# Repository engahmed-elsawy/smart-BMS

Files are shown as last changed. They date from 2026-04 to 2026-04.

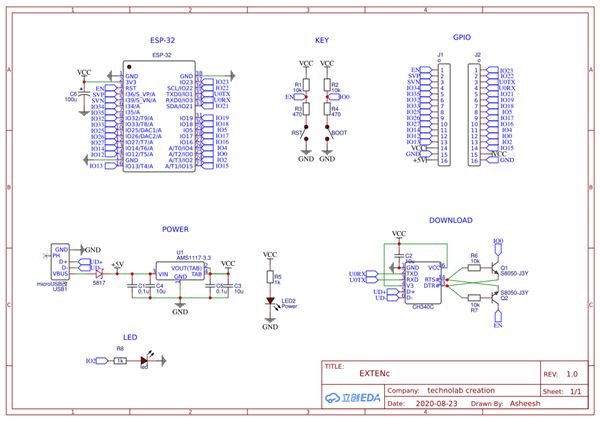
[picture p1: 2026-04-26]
PCB Design/f37d51bfc36943d1b52e4bf3738da4ba_1.jpg

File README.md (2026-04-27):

# ESP32 Smart BMS

An open-source Battery Management System for 6S Li-ion packs built around an ESP32.
The project covers hardware design, embedded firmware, and a planned machine learning
pipeline that will train on the data the system collects.

---

## Project Status

| Phase | Status |
|---|---|
| Hardware design (schematic + PCB) | ✅ Done |
| Firmware v1 — Coulomb Counting + Web Dashboard | ✅ Done |
| Firmware v2 — MQTT data pipeline | ✅ Done |
| ML model — SOC / SOH estimation | 🔜 Planned |

---

## Repository Structure

```
esp32-smart-bms/
│
├── hardware/
│   └── schematic/               BMS schematic (KiCad / PDF)
│
├── esp32_bms_coulomb/           Firmware v1 — Web dashboard only
│   ├── esp32_bms_coulomb.cpp
│   └── README.md
│
├── esp32_bms_mqtt/              Firmware v2 — Web dashboard + MQTT
│   ├── esp32_bms_coulomb_mqtt.cpp
│   └── README.md
│
└── README.md                    ← this file
```

---

## What the System Does

```
┌─────────────────────────────────────────────────────────┐
│                     6S Li-ion Pack                      │
│  Cell 1 │ Cell 2 │ Cell 3 │ Cell 4 │ Cell 5 │ Cell 6   │
└────┬─────────┬────────┬────────┬────────┬────────┬──────┘
     │         │        │        │        │        │
     └─────────┴────────┴───── CD4051 ────┴────────┘
                                  │
                              ESP32 ADC
                                  │
              ┌───────────────────┼───────────────────┐
              │                   │                   │
        Web Dashboard          MQTT Broker        Serial Monitor
        (browser, live)     (Home Assistant /    (115200 baud)
                              Grafana / ML)
                                  │
                          ┌───────┴───────┐
                          │  (planned)    │
                       Dataset CSV    ML Model
                      (SOC / SOH /   (TensorFlow
                       temperature)    Lite / sklearn)
```

---

## Hardware Overview

### Core Components

| Component | Role |
|---|---|
| ESP32 DevKit | Main MCU — ADC, Wi-Fi, control logic |
| CD4051 | 8-channel analog MUX — reads all cells through one ADC pin |
| ACS712 (or similar) | Current sensor — measures pack charge / discharge current |
| Voltage dividers | Scale each cell voltage and pack voltage down to ≤ 3.3 V |
| MOSFETs / transistors | Balance outputs — one per cell |

### Key Design Decisions

**Single ADC pin via MUX** — The CD4051 lets the ESP32 read 8 analog channels
through a single ADC input. This saves GPIOs and avoids the inter-channel
crosstalk that comes from using multiple ADC pins simultaneously on the ESP32.

**All analog signals ≤ 3.3 V** — The ESP32 ADC is not 5 V tolerant.
Every voltage divider and sensor output is designed to stay within 0–3.3 V.

**ADC1 only** — ADC2 on the ESP32 is shared with the Wi-Fi radio and gives
unreliable readings when Wi-Fi is active. `PIN_MUX_OUT` is wired to a GPIO
in the ADC1 group (GPIO 32–39).

**Hardware schematic** is in the `hardware/schematic/` folder.

---

## Firmware

### v1 — Web Dashboard (`esp32_bms_coulomb/`)

Standalone firmware. No external services needed.

- Reads all 8 MUX channels every 300 ms
- Coulomb Counting SOC with voltage re-sync at rest
- Auto cell balancing (configurable thresholds)
- Live browser dashboard with 4 Chart.js graphs — updates every second
- JSON API at `/api/status` and `/api/history`

### v2 — MQTT (`esp32_bms_mqtt/`)

Everything in v1, plus:

- Publishes to MQTT broker every 5 seconds
- Individual topics per value (`bms/soc`, `bms/cell/1`, etc.)
- Subscribes to command topics for remote balance control
- Compatible with Home Assistant, Node-RED, Grafana, and any MQTT client
- **All published data is logged by the broker** — this is the dataset that
  will feed the ML pipeline

See each folder's `README.md` for full setup instructions.

---

## MQTT Data Format

Every publish cycle sends these topics:

```
bms/status         →  full JSON snapshot
bms/soc            →  67.4
bms/pack_voltage   →  24.350
bms/pack_current   →  -2.100
bms/cell/1  …  /6  →  4.058  (one topic per cell)
bms/charged_ah     →  1.2340
bms/discharged_ah  →  3.5670
```

To log everything to a CSV file using Node-RED or a simple subscriber:

```bash
# log all bms topics to a file
mosquitto_sub -h 192.168.1.100 -t "bms/#" -v >> bms_log.txt
```

---

## ML Pipeline (Planned)

The MQTT broker accumulates time-series data across real charge / discharge cycles.
That dataset will be used to train a model that estimates SOC and SOH more
accurately than the current voltage-table approach.

### Planned Features

- **Better SOC estimation** — replace the voltage lookup table with a learned
  model that accounts for temperature, aging, and load history
- **SOH (State of Health)** — track capacity fade over hundreds of cycles
- **Anomaly detection** — flag unusual cell behavior (high self-discharge,
  internal short, accelerated aging)
- **Remaining useful life (RUL)** — predict how many cycles the pack has left

### Planned Stack

```
Data collection  →  MQTT broker  →  CSV / InfluxDB
Feature engineering  →  Python (pandas, numpy)
Model training   →  scikit-learn / TensorFlow / PyTorch
Deployment       →  TensorFlow Lite on ESP32  or  inference on a Pi / server
```

### Features the Model Will Use

| Feature | Source |
|---|---|
| Cell voltages (V1–V6) | `bms/cell/1` … `/6` |
| Pack current (A) | `bms/pack_current` |
| Pack voltage (V) | `bms/pack_voltage` |
| SOC from Coulomb Counting | `bms/soc` |
| Charged Ah | `bms/charged_ah` |
| Discharged Ah | `bms/discharged_ah` |
| Timestamp | logged by subscriber |
| Temperature (future) | planned sensor addition |

### Data Collection Advice

The more cycles logged, the better the model. To build a useful dataset:

1. Flash the v2 MQTT firmware.
2. Set up a broker and a subscriber that appends every message to a CSV with a timestamp.
3. Run the pack through full charge / discharge cycles under realistic loads.
4. Aim for at least 20–30 full cycles before starting model training.

---

## Quick Start

### 1. Flash the firmware

1. Install [Arduino IDE 2.x](https://www.arduino.cc/en/software).
2. Add the ESP32 board package URL in `File → Preferences`:
   ```
   https://raw.githubusercontent.com/espressif/arduino-esp32/gh-pages/package_esp32_index.json
   ```
3. Open `esp32_bms_coulomb/esp32_bms_coulomb.cpp`.
4. Set your Wi-Fi credentials and GPIO pins in the **USER CONFIG** section.
5. Set `packCapacityAh` to your pack's real capacity.
6. Flash to your ESP32.

### 2. Open the dashboard

Find the IP in Serial Monitor (115200 baud) and open it in a browser.

### 3. Add MQTT (optional)

Switch to the `esp32_bms_mqtt/` version, install **PubSubClient**, set
`MQTT_BROKER` to your broker's IP, and reflash.

---

## Calibration Checklist

Before trusting the readings, go through this checklist:

- [ ] Measure each cell voltage with a multimeter and calculate the correct `cellScale[i]`
- [ ] Measure pack voltage and calculate the correct `packScale`
- [ ] Verify current sensor zero-current offset matches `currentOffsetV`
- [ ] Set `packCapacityAh` to the actual rated capacity of your cells
- [ ] Update the SOC voltage table if your cells have a different chemistry

---

## Contributing

Pull requests are welcome. If you are working on the ML pipeline, data collection
scripts, or a new sensor integration, open an issue first to discuss the approach.

---

## License

MIT

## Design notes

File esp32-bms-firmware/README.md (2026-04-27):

# ESP32 BMS — Coulomb Counting + Live Web Dashboard

ESP32 firmware for monitoring a 6S Li-ion battery pack.
Reads 6 cells + pack current + pack voltage through a CD4051 analog MUX,
estimates SOC using Coulomb Counting, and serves a live dashboard in the browser.

---

## Repository Structure

```
esp32_bms_coulomb/
└── esp32_bms_coulomb.cpp
```

---

## Requirements

### Hardware

| Component | Details |
|---|---|
| ESP32 DevKit | Any standard ESP32 board |
| CD4051 | 8-channel analog multiplexer |
| Current sensor | ACS712 or similar (output 0–3.3 V) |
| Voltage dividers | One per cell + one for pack — output must be ≤ 3.3 V |
| Balancing circuit | MOSFET or transistor per cell |

### Software

- [Arduino IDE](https://www.arduino.cc/en/software) version 2.x
- **ESP32 board package** — in Arduino IDE:  
  `File → Preferences → Additional boards manager URLs`, add:
  ```
  https://raw.githubusercontent.com/espressif/arduino-esp32/gh-pages/package_esp32_index.json
  ```
  Then `Tools → Board → Boards Manager`, search for **esp32** and install it.

No additional libraries are needed — the code uses `WiFi.h` and `WebServer.h`
which ship with the ESP32 package.

---

## Configuration

Open `esp32_bms_coulomb.cpp` and edit the **USER CONFIG** section at the top.

### 1. Wi-Fi credentials

```cpp
const char* WIFI_SSID = "YOUR_WIFI_SSID";    // your Wi-Fi network name
const char* WIFI_PASS = "YOUR_WIFI_PASSWORD"; // your Wi-Fi password
```

### 2. GPIO pin mapping

```cpp
static const int PIN_MUX_S0  = 25;   // MUX select bit 0
static const int PIN_MUX_S1  = 26;   // MUX select bit 1
static const int PIN_MUX_S2  = 27;   // MUX select bit 2
static const int PIN_MUX_OUT = 34;   // MUX output → ADC (use GPIO 32–39 only)

static const int PIN_BAL_1 = 16;     // balance output — cell 1
static const int PIN_BAL_2 = 17;
static const int PIN_BAL_3 = 18;
static const int PIN_BAL_4 = 19;
static const int PIN_BAL_5 = 21;
static const int PIN_BAL_6 = 22;
```

Change these numbers to match your actual wiring.

### 3. Voltage calibration

```cpp
// cell_V = adc_V × cellScale  — one scale factor per cell
float cellScale[6] = { 1.400f, 1.400f, 1.400f, 1.400f, 1.400f, 1.400f };

// pack_V = adc_V × packScale
float packScale = 9.125f;

// current sensor:  I(A) = (adc_V - offset) × gain
// ACS712-20A example: offset = 1.65 V, gain = 10.0 A/V
float currentOffsetV   = 1.650f;
float currentGainAperV = 10.000f;
```

**How to calibrate `cellScale`:**  
Measure the real cell voltage with a multimeter, then read the ADC voltage
for the same channel from Serial Monitor.
```
cellScale = real_voltage / adc_voltage
```
Example: multimeter reads 3.80 V, ADC reads 0.271 V → `cellScale = 14.02`

### 4. Pack capacity (Coulomb Counting)

```cpp
// Set this to the real capacity of your pack in Ah
float packCapacityAh = 10.0f;
```

---

## MUX Channel Mapping (CD4051)

| Channel | Signal | Description |
|---|---|---|
| CH0 | ADC_C1 | Cell 1 voltage |
| CH1 | ADC_C2 | Cell 2 voltage |
| CH2 | ADC_C3 | Cell 3 voltage |
| CH3 | ADC_C4 | Cell 4 voltage |
| CH4 | ADC_C5 | Cell 5 voltage |
| CH5 | ADC_C6 | Cell 6 voltage |
| CH6 | ADC_ip | Pack current |
| CH7 | ADC_vb | Pack voltage |

---

## Web Dashboard

After flashing, open Serial Monitor at **115200 baud**. You will see:

```
Connected — IP: 192.168.1.45
HTTP server started.
```

Open a browser on any device on the same network and go to:

```
http://192.168.1.45/
```

The page updates every second without reloading.

### What the dashboard shows

- **Pack Voltage** and **Pack Current** — live readings
- **SOC (Coulomb Counting)** with a color bar (green → yellow → red as it drops)
- **SOC (Voltage)** — reference value for comparison
- **Charged Ah / Discharged Ah** — cumulative totals since boot
- **6 cell cards** — individual voltages, highlighted when balancing is active
- **4 live charts** — SOC %, Pack Voltage, Pack Current, and all Cell Voltages

### HTTP Endpoints

| URL | Description |
|---|---|
| `http://[IP]/` | Main live dashboard |
| `http://[IP]/api/status` | Full JSON snapshot of all values |
| `http://[IP]/api/history` | Last 200 data points as arrays (used by charts) |
| `http://[IP]/balance/off` | Turn off all balance outputs |
| `http://[IP]/balance/auto/on` | Enable automatic balancing |
| `http://[IP]/balance/auto/off` | Disable automatic balancing |
| `http://[IP]/balance/set?cell=3&state=1` | Manually switch one cell on (state=1) or off (state=0) |

---

## Coulomb Counting — How It Works

1. **First boot:** SOC is seeded from the voltage lookup table since no current history exists yet.
2. **During operation:** integrates `dSOC = I × dt / capacity × 100` every 300 ms.
   - Positive current (charging) → multiplied by `chargeEfficiency`.
   - Negative current (discharging) → divided by `dischargeEfficiency`.
3. **Rest re-sync:** when `|I| < 0.2 A` for 60 consecutive seconds the pack is
   considered at rest. The voltage-based SOC then gently corrects any accumulated
   integration drift using a 90 % CC + 10 % voltage blend per cycle.

---

## Serial Monitor Output

A report is printed every 2 seconds:

```
====================================================
Samples : 1547
Pack    : 24.350 V | -2.100 A
SOC (CC): 67.45 %  |  SOC (V): 65.20 %
Charged : 0.0000 Ah  |  Discharged: 0.1234 Ah
Cell 1  : 4.058 V  BAL=OFF
Cell 2  : 4.061 V  BAL=OFF
Cell 3  : 4.055 V  BAL=OFF
Cell 4  : 4.059 V  BAL=OFF
Cell 5  : 4.060 V  BAL=OFF
Cell 6  : 4.057 V  BAL=OFF
Raw ADC:
  CH0 (ADC_C1): raw=336  adc=0.2710 V
  ...
```

---

## Next Step

If you need to push data to Home Assistant, Grafana, or control the BMS
remotely over the network — see the MQTT version in the `esp32_bms_mqtt` folder.

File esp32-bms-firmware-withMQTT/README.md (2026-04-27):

# ESP32 BMS — Coulomb Counting + Live Dashboard + MQTT

Extended version of the BMS firmware that adds MQTT on top of the web dashboard.
The ESP32 publishes live battery data to a broker every 5 seconds and accepts
remote commands to control cell balancing from any device on the network.

> The web dashboard from `esp32_bms_coulomb` is still fully functional in this
> version — MQTT is added on top without removing anything.

---

## Repository Structure

```
esp32_bms_mqtt/
└── esp32_bms_coulomb.cpp
```

---

## Additional Requirements

### Extra Library

**PubSubClient** by Nick O'Leary

**Arduino IDE:**  
`Sketch → Include Library → Manage Libraries` → search for `PubSubClient` → Install

**PlatformIO** — add to `platformio.ini`:
```ini
lib_deps = knolleary/PubSubClient @ ^2.8
```

### MQTT Broker

You need a running MQTT broker accessible from the ESP32.

| Option | Best for | Setup |
|---|---|---|
| **Mosquitto** on Raspberry Pi or PC | Permanent local use | `sudo apt install mosquitto mosquitto-clients` |
| **Home Assistant** built-in broker | If you already run HA | Enable the Mosquitto add-on inside HA |
| **HiveMQ Cloud** (free tier) | Cloud access, no local server | [hivemq.com/mqtt-cloud-broker](https://www.hivemq.com/mqtt-cloud-broker/) |
| **test.mosquitto.org** | Quick testing only | Public broker — do not use in production |

---

## Configuration

Open `esp32_bms_coulomb.cpp` and edit the **USER CONFIG** section at the top.

### 1. Wi-Fi credentials

```cpp
const char* WIFI_SSID = "YOUR_WIFI_SSID";    // your Wi-Fi network name
const char* WIFI_PASS = "YOUR_WIFI_PASSWORD"; // your Wi-Fi password
```

### 2. MQTT broker address ← most important step

```cpp
const char* MQTT_BROKER   = "192.168.1.100"; // ← IP or hostname of your broker
const uint16_t MQTT_PORT  = 1883;            // default MQTT port (use 8883 for TLS)
const char* MQTT_USER     = "";              // leave empty if no authentication
const char* MQTT_PASS_STR = "";              // leave empty if no authentication
const char* MQTT_CLIENT_ID    = "esp32_bms_01"; // unique name for this device
const char* MQTT_TOPIC_PREFIX = "bms";          // all topics will start with this
```

**How to find your broker IP:**

- **Mosquitto on Raspberry Pi:** the broker IP is the Pi's IP address.  
  Run `hostname -I` in the Pi terminal to find it.
- **Mosquitto on Windows/Linux PC:** use the machine's local IP.  
  On Windows: `ipconfig` in Command Prompt → look for IPv4 Address.  
  On Linux: `ip a` → look for your network interface IP.
- **Home Assistant:** go to `Settings → System → Network` to find the HA IP.
- **HiveMQ Cloud:** your dashboard provides a hostname — paste it in place of the IP  
  and change `MQTT_PORT` to `8883`. TLS support requires additional setup.
- **Quick test (no broker):** set `MQTT_BROKER = "test.mosquitto.org"` temporarily.

**If your broker requires a username and password:**

```cpp
const char* MQTT_USER     = "myusername";
const char* MQTT_PASS_STR = "mypassword";
```

### 3. Publish interval

```cpp
// How often to publish data in milliseconds — keep at 1000 or above
const uint32_t MQTT_PUBLISH_INTERVAL_MS = 5000;  // every 5 seconds
```

### 4. Disable MQTT without removing the code

```cpp
bool mqttEnabled = false;   // web dashboard still works normally
```

---

## Topics Published by the ESP32

All topics start with the prefix defined in `MQTT_TOPIC_PREFIX` (default: `bms`).

| Topic | Type | Example value |
|---|---|---|
| `bms/status` | Full JSON | `{"samples":1200,"pack_voltage":24.35,...}` |
| `bms/soc` | Number | `67.4` |
| `bms/pack_voltage` | Number | `24.350` |
| `bms/pack_current` | Number | `-2.100` |
| `bms/cell/1` | Number | `4.058` |
| `bms/cell/2` | Number | `4.061` |
| `bms/cell/3` | Number | `4.055` |
| `bms/cell/4` | Number | `4.059` |
| `bms/cell/5` | Number | `4.060` |
| `bms/cell/6` | Number | `4.057` |
| `bms/charged_ah` | Number | `1.2340` |
| `bms/discharged_ah` | Number | `3.5670` |

---

## Command Topics (ESP32 subscribes)

Send a message to these topics to control the BMS remotely.

| Topic | Payload | Result |
|---|---|---|
| `bms/cmd/balance_auto` | `ON` | Enable automatic balancing |
| `bms/cmd/balance_auto` | `OFF` | Disable automatic balancing |
| `bms/cmd/balance_all` | `OFF` | Force all balance outputs off |
| `bms/cmd/balance_set` | `3:1` | Turn cell 3 balance on manually |
| `bms/cmd/balance_set` | `3:0` | Turn cell 3 balance off manually |

**Examples using `mosquitto_pub` from a terminal:**

```bash
# Enable auto balance
mosquitto_pub -h 192.168.1.100 -t "bms/cmd/balance_auto" -m "ON"

# Turn off all balancing
mosquitto_pub -h 192.168.1.100 -t "bms/cmd/balance_all" -m "OFF"

# Manually turn on cell 2
mosquitto_pub -h 192.168.1.100 -t "bms/cmd/balance_set" -m "2:1"

# Manually turn off cell 2
mosquitto_pub -h 192.168.1.100 -t "bms/cmd/balance_set" -m "2:0"
```

**Monitor all topics from a terminal:**

```bash
# Subscribe to everything under the bms/ prefix
mosquitto_sub -h 192.168.1.100 -t "bms/#" -v

# Watch SOC only
mosquitto_sub -h 192.168.1.100 -t "bms/soc"
```

---

## Home Assistant Integration

Add the following to your `configuration.yaml`:

```yaml
mqtt:
  sensor:
    - name: "BMS SOC"
      state_topic: "bms/soc"
      unit_of_measurement: "%"
      device_class: battery

    - name: "BMS Pack Voltage"
      state_topic: "bms/pack_voltage"
      unit_of_measurement: "V"
      device_class: voltage

    - name: "BMS Pack Current"
      state_topic: "bms/pack_current"
      unit_of_measurement: "A"
      device_class: current

    - name: "BMS Charged Ah"
      state_topic: "bms/charged_ah"
      unit_of_measurement: "Ah"

    - name: "BMS Discharged Ah"
      state_topic: "bms/discharged_ah"
      unit_of_measurement: "Ah"

    - name: "BMS Cell 1"
      state_topic: "bms/cell/1"
      unit_of_measurement: "V"

    - name: "BMS Cell 2"
      state_topic: "bms/cell/2"
      unit_of_measurement: "V"

    - name: "BMS Cell 3"
      state_topic: "bms/cell/3"
      unit_of_measurement: "V"

    - name: "BMS Cell 4"
      state_topic: "bms/cell/4"
      unit_of_measurement: "V"

    - name: "BMS Cell 5"
      state_topic: "bms/cell/5"
      unit_of_measurement: "V"

    - name: "BMS Cell 6"
      state_topic: "bms/cell/6"
      unit_of_measurement: "V"

  switch:
    - name: "BMS Auto Balance"
      command_topic: "bms/cmd/balance_auto"
      payload_on: "ON"
      payload_off: "OFF"
```

---

## Serial Monitor Output

MQTT connection status is printed alongside the normal data report:

```
[MQTT] Connecting to 192.168.1.100… connected.
[MQTT] Subscribed to cmd topics.
====================================================
Samples : 1547
Pack    : 24.350 V | -2.100 A
SOC (CC): 67.45 %  |  SOC (V): 65.20 %
...
```

If the connection drops, the firmware retries automatically every 10 seconds:

```
[MQTT] Connecting to 192.168.1.100… failed (rc=-2) — will retry.
```

---

## Suggested Repository Structure

```
esp32-bms-firmware/
│
├── esp32_bms_coulomb/          ← v1 — Web dashboard only
│   ├── esp32_bms_coulomb.cpp
│   └── README.md
│
└── esp32_bms_mqtt/             ← v2 — Web dashboard + MQTT
    ├── esp32_bms_coulomb_mqtt.cpp
    └── README.md               ← this file

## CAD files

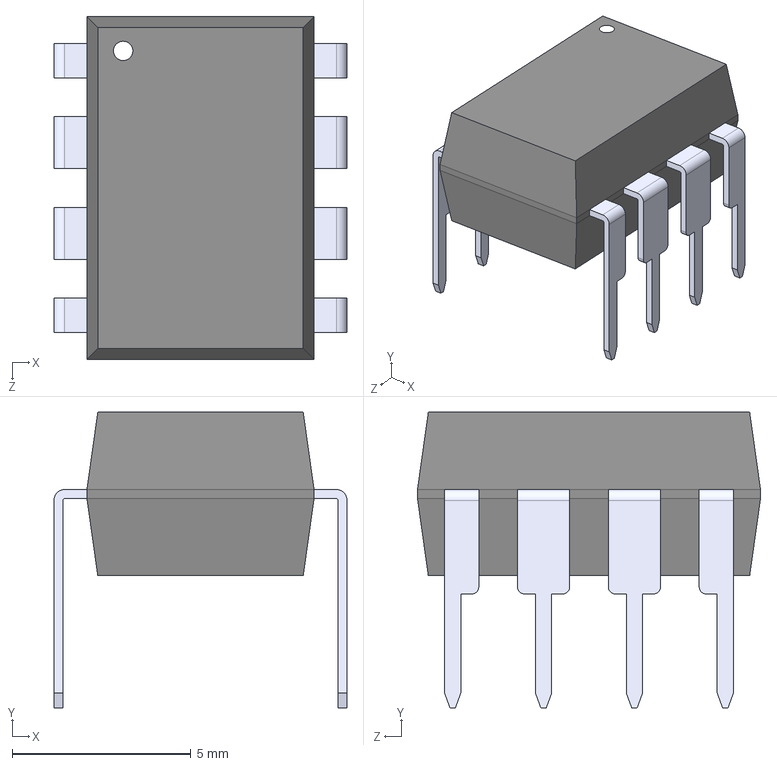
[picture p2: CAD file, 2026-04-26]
PCB Design/LM358P.STEP
8.19 x 8.26 x 9.59 mm

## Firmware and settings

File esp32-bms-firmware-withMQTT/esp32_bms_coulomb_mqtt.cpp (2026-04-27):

#include <WiFi.h>
#include <WebServer.h>
#include <PubSubClient.h>
#include <math.h>

/*
  ESP32 BMS Firmware — v2 — Coulomb Counting + Web Dashboard + MQTT
  ==================================================================
  Hardware: as per schematic (Ahmed Hatem Elsawy — 27/4/2026)
    - CD4051BM  8-ch MUX  (S0=IO25, S1=IO26, S2=IO27, OUT→GPIO34)
    - LM358P    differential cell voltage buffers (gain=0.5 per cell)
    - LM358P    pack voltage buffer  (R49=13K / R51=1.6K divider)
    - ACS712-30A current sensor, VCC=5V, through LM358 gain-2 amp
      + external 18K/33K voltage divider to protect ESP32 ADC
    - IRLZ44N   balancing MOSFETs via optocouplers

  Required library: PubSubClient by Nick O'Leary
    Arduino IDE  → Sketch → Include Library → Manage Libraries → "PubSubClient"
    PlatformIO   → lib_deps = knolleary/PubSubClient @ ^2.8

  Current sensor signal chain:
    ACS712-30A (VCC=5V) → zero=2.5V, sensitivity=66mV/A
    → LM358 gain-2  → zero=5.0V, gain=132mV/A
    → 18K/33K divider (×0.647) → zero=3.235V, gain=85.4mV/A
    → ESP32 ADC (safe ≤3.3V)
    currentGainAperV = 1 / 0.0854 = 11.7 A/V

  Cell voltage signal chain:
    Cell differential → LM358 unity buffer → 1M/1M divider → ADC
    cellScale = 2.0

  MUX channel mapping:
    CH0=ADC_C1, CH1=ADC_C2, CH2=ADC_C3, CH3=ADC_C4,
    CH4=ADC_C5, CH5=ADC_C6, CH6=ADC_ip, CH7=ADC_vb

  MQTT topics published  (prefix = MQTT_TOPIC_PREFIX, default "bms"):
    bms/status         full JSON snapshot
    bms/soc            SOC % (Coulomb)
    bms/pack_voltage   pack V
    bms/pack_current   pack A
    bms/cell/1…6       individual cell voltages
    bms/charged_ah     cumulative Ah in
    bms/discharged_ah  cumulative Ah out

  MQTT command topics (subscribed):
    bms/cmd/balance_auto   ON | OFF
    bms/cmd/balance_all    OFF
    bms/cmd/balance_set    "N:S"  e.g. "3:1" or "3:0"
*/

// =====================================================================
// USER CONFIG
// =====================================================================
const char* WIFI_SSID = "YOUR_WIFI_SSID";
const char* WIFI_PASS = "YOUR_WIFI_PASSWORD";

// ── MQTT ─────────────────────────────────────────────────────────────
const char*    MQTT_BROKER        = "192.168.1.100"; // ← your broker IP
const uint16_t MQTT_PORT          = 1883;
const char*    MQTT_USER          = "";   // leave empty if no auth
const char*    MQTT_PASS_STR      = "";
const char*    MQTT_CLIENT_ID     = "esp32_bms_01";
const char*    MQTT_TOPIC_PREFIX  = "bms";

const uint32_t MQTT_PUBLISH_INTERVAL_MS = 5000;  // publish every 5 s
bool mqttEnabled = true;   // set false to run without MQTT
// ─────────────────────────────────────────────────────────────────────

// GPIO pins — matched to schematic
static const int PIN_MUX_S0  = 25;
static const int PIN_MUX_S1  = 26;
static const int PIN_MUX_S2  = 27;
static const int PIN_MUX_OUT = 34;

static const int PIN_BAL_1 = 16;
static const int PIN_BAL_2 = 17;
static const int PIN_BAL_3 = 18;
static const int PIN_BAL_4 = 19;
static const int PIN_BAL_5 = 21;
static const int PIN_BAL_6 = 22;

static const int PIN_STATUS_LED = 2;

static const uint8_t  ADC_SAMPLES_PER_READ = 16;
static const uint16_t MUX_SETTLE_MS        = 5;
static const float    ADC_VREF             = 3.30f;
static const int      ADC_MAX              = 4095;

// =====================================================================
// CALIBRATION
// =====================================================================
float cellScale[6] = { 2.0f, 2.0f, 2.0f, 2.0f, 2.0f, 2.0f };
float packScale    = 9.125f;

float currentOffsetV   = 3.235f;
float currentGainAperV = 11.70f;

// =====================================================================
// COULOMB COUNTING CONFIG
// =====================================================================
float packCapacityAh = 10.0f;   // ← set your real pack capacity in Ah

float chargeEfficiency    = 0.98f;
float dischargeEfficiency = 1.00f;

float    ccResyncCurrentThreshA = 0.20f;
uint32_t ccResyncRestDurationMs = 60000UL;

// =====================================================================
// SOC VOLTAGE TABLE
// =====================================================================
static const uint8_t SOC_TABLE_SIZE = 11;

float socVoltageTable[SOC_TABLE_SIZE] = {
  3.00f, 3.20f, 3.30f, 3.40f, 3.50f,
  3.60f, 3.70f, 3.80f, 3.95f, 4.10f, 4.20f
};
float socPercentTable[SOC_TABLE_SIZE] = {
   0.0f, 10.0f, 20.0f, 30.0f, 40.0f,
  50.0f, 60.0f, 70.0f, 80.0f, 90.0f, 100.0f
};

bool  useMinCellForSocSafety = true;
float socLowClampCellV       = 3.00f;
float socHighClampCellV      = 4.20f;

// =====================================================================
// BALANCING CONFIG
// =====================================================================
bool  autoBalanceEnabled         = false;
float balanceStartVoltage        = 4.10f;
float balanceStopDelta           = 0.03f;
float minPackVoltageForBalancing = 20.0f;

// =====================================================================
// HISTORY RING BUFFER
// =====================================================================
static const uint16_t HIST_SIZE = 200;

struct HistPoint {
  uint32_t t;
  float    packV, packI, soc;
  float    cell[6];
};

HistPoint histBuf[HIST_SIZE];
uint16_t  histHead  = 0;
uint16_t  histCount = 0;

// =====================================================================
// INTERNAL STATE
// =====================================================================
WebServer    server(80);
WiFiClient   wifiClientMqtt;
PubSubClient mqttClient(wifiClientMqtt);

struct BmsData {
  uint16_t raw[8];
  float    adcVoltage[8];
  float    cellVoltage[6];
  float    packVoltage, packCurrent;
  float    avgCellVoltage, minCellVoltage, maxCellVoltage;
  float    socPercent, socVoltage;
  float    chargedAh, dischargedAh;
  bool     balanceState[6];
  unsigned long sampleCounter;
};

BmsData bms;

bool     ccInitialized  = false;
float    ccSocPercent   = 50.0f;
uint32_t ccLastSampleMs = 0;
uint32_t ccRestStartMs  = 0;
bool     ccInRest       = false;

const int balancePins[6] = {
  PIN_BAL_1, PIN_BAL_2, PIN_BAL_3, PIN_BAL_4, PIN_BAL_5, PIN_BAL_6
};

const char* muxChannelNames[8] = {
  "ADC_C1","ADC_C2","ADC_C3","ADC_C4",
  "ADC_C5","ADC_C6","ADC_ip","ADC_vb"
};

unsigned long printIntervalMs = 2000;

// =====================================================================
// HELPERS
// =====================================================================
void setMuxChannel(uint8_t ch) {
  digitalWrite(PIN_MUX_S0,(ch&0x01)?HIGH:LOW);
  digitalWrite(PIN_MUX_S1,(ch&0x02)?HIGH:LOW);
  digitalWrite(PIN_MUX_S2,(ch&0x04)?HIGH:LOW);
}

uint16_t readMuxRaw(uint8_t ch) {
  setMuxChannel(ch); delay(MUX_SETTLE_MS);
  uint32_t sum=0;
  for(uint8_t i=0;i<ADC_SAMPLES_PER_READ;i++){sum+=analogRead(PIN_MUX_OUT);delayMicroseconds(200);}
  return (uint16_t)(sum/ADC_SAMPLES_PER_READ);
}

float rawToVoltage(uint16_t raw){ return ((float)raw*ADC_VREF)/(float)ADC_MAX; }

void setBalance(uint8_t idx,bool on){
  if(idx>=6)return;
  bms.balanceState[idx]=on;
  digitalWrite(balancePins[idx],on?HIGH:LOW);
}

void allBalanceOff(){ for(uint8_t i=0;i<6;i++) setBalance(i,false); }

float getMaxCellVoltage(){
  float v=bms.cellVoltage[0];
  for(uint8_t i=1;i<6;i++) if(bms.cellVoltage[i]>v) v=bms.cellVoltage[i];
  return v;
}
float getMinCellVoltage(){
  float v=bms.cellVoltage[0];
  for(uint8_t i=1;i<6;i++) if(bms.cellVoltage[i]<v) v=bms.cellVoltage[i];
  return v;
}
float getAverageCellVoltage(){
  float s=0.0f;
  for(uint8_t i=0;i<6;i++) s+=bms.cellVoltage[i];
  return s/6.0f;
}
float clampf(float x,float lo,float hi){ return x<lo?lo:(x>hi?hi:x); }

float interpolateSocFromCellVoltage(float cellV){
  cellV=clampf(cellV,socLowClampCellV,socHighClampCellV);
  if(cellV<=socVoltageTable[0]) return socPercentTable[0];
  for(uint8_t i=1;i<SOC_TABLE_SIZE;i++){
    if(cellV<=socVoltageTable[i]){
      float x0=socVoltageTable[i-1],x1=socVoltageTable[i];
      float y0=socPercentTable[i-1],y1=socPercentTable[i];
      return y0+(cellV-x0)/(x1-x0)*(y1-y0);
    }
  }
  return socPercentTable[SOC_TABLE_SIZE-1];
}

// =====================================================================
// COULOMB COUNTING
// =====================================================================
void updateCoulombCounting() {
  uint32_t now=millis();
  if(!ccInitialized){
    float vIn=bms.avgCellVoltage;
    if(useMinCellForSocSafety) vIn=min(bms.avgCellVoltage,bms.minCellVoltage+0.03f);
    ccSocPercent=interpolateSocFromCellVoltage(vIn);
    bms.socPercent=ccSocPercent;
    ccLastSampleMs=ccRestStartMs=now;
    ccInitialized=true; return;
  }
  float dtH=(float)(now-ccLastSampleMs)/3600000.0f;
  ccLastSampleMs=now;
  float I=bms.packCurrent;
  if(I>0.0f){ float dAh=I*dtH*chargeEfficiency; bms.chargedAh+=dAh; ccSocPercent+=(dAh/packCapacityAh)*100.0f; }
  else if(I<0.0f){ float dAh=fabsf(I)*dtH/dischargeEfficiency; bms.dischargedAh+=dAh; ccSocPercent-=(dAh/packCapacityAh)*100.0f; }
  ccSocPercent=clampf(ccSocPercent,0.0f,100.0f);
  bool resting=(fabsf(I)<ccResyncCurrentThreshA);
  if(resting){
    if(!ccInRest){ccInRest=true;ccRestStartMs=now;}
    if((now-ccRestStartMs)>=ccResyncRestDurationMs){
      float vIn=bms.avgCellVoltage;
      if(useMinCellForSocSafety) vIn=min(bms.avgCellVoltage,bms.minCellVoltage+0.03f);
      ccSocPercent=ccSocPercent*0.90f+interpolateSocFromCellVoltage(vIn)*0.10f;
    }
  } else { ccInRest=false; }
  bms.socPercent=ccSocPercent;
  float vIn=bms.avgCellVoltage;
  if(useMinCellForSocSafety) vIn=min(bms.avgCellVoltage,bms.minCellVoltage+0.03f);
  bms.socVoltage=interpolateSocFromCellVoltage(vIn);
}

// =====================================================================
// AUTO BALANCING
// =====================================================================
void updateAutoBalancing(){
  if(!autoBalanceEnabled){allBalanceOff();return;}
  if(bms.packVoltage<minPackVoltageForBalancing){allBalanceOff();return;}
  float maxC=getMaxCellVoltage(), minC=getMinCellVoltage();
  if((maxC-minC)<balanceStopDelta){allBalanceOff();return;}
  for(uint8_t i=0;i<6;i++){
    bool en=(bms.cellVoltage[i]>=balanceStartVoltage)&&((bms.cellVoltage[i]-minC)>=balanceStopDelta);
    setBalance(i,en);
  }
}

// =====================================================================
// SAMPLING
// =====================================================================
void sampleAllChannels(){
  for(uint8_t ch=0;ch<8;ch++){bms.raw[ch]=readMuxRaw(ch);bms.adcVoltage[ch]=rawToVoltage(bms.raw[ch]);}
  for(uint8_t i=0;i<6;i++) bms.cellVoltage[i]=bms.adcVoltage[i]*cellScale[i];
  bms.packCurrent=(bms.adcVoltage[6]-currentOffsetV)*currentGainAperV;
  bms.packVoltage=bms.adcVoltage[7]*packScale;
  bms.minCellVoltage=getMinCellVoltage();
  bms.maxCellVoltage=getMaxCellVoltage();
  bms.avgCellVoltage=getAverageCellVoltage();
  updateCoulombCounting();
  updateAutoBalancing();
  bms.sampleCounter++;
  histBuf[histHead]={millis(),bms.packVoltage,bms.packCurrent,bms.socPercent,
    {bms.cellVoltage[0],bms.cellVoltage[1],bms.cellVoltage[2],
     bms.cellVoltage[3],bms.cellVoltage[4],bms.cellVoltage[5]}};
  histHead=(histHead+1)%HIST_SIZE;
  if(histCount<HIST_SIZE) histCount++;
}

// =====================================================================
// JSON
// =====================================================================
String jsonStatus(){
  String s="{";
  s+="\"samples\":"+String(bms.sampleCounter)+",";
  s+="\"pack_voltage\":"+String(bms.packVoltage,3)+",";
  s+="\"pack_current\":"+String(bms.packCurrent,3)+",";
  s+="\"avg_cell_v\":"+String(bms.avgCellVoltage,3)+",";
  s+="\"min_cell_v\":"+String(bms.minCellVoltage,3)+",";
  s+="\"max_cell_v\":"+String(bms.maxCellVoltage,3)+",";
  s+="\"soc_cc\":"+String(bms.socPercent,2)+",";
  s+="\"soc_v\":"+String(bms.socVoltage,2)+",";
  s+="\"charged_ah\":"+String(bms.chargedAh,4)+",";
  s+="\"discharged_ah\":"+String(bms.dischargedAh,4)+",";
  s+="\"cell_voltages\":[";
  for(uint8_t i=0;i<6;i++){s+=String(bms.cellVoltage[i],3);if(i<5)s+=",";}
  s+="],\"balance\":[";
  for(uint8_t i=0;i<6;i++){s+=bms.balanceState[i]?"true":"false";if(i<5)s+=",";}
  s+="],\"adc_raw\":[";
  for(uint8_t i=0;i<8;i++){s+=String(bms.raw[i]);if(i<7)s+=",";}
  s+="]}";
  return s;
}

String jsonHistory(){
  uint16_t start=(histCount<HIST_SIZE)?0:histHead;
  String s="{\"t\":[";
  for(uint16_t k=0;k<histCount;k++){uint16_t idx=(start+k)%HIST_SIZE;s+=String(histBuf[idx].t);if(k<histCount-1)s+=",";}
  s+="],\"packV\":[";
  for(uint16_t k=0;k<histCount;k++){uint16_t idx=(start+k)%HIST_SIZE;s+=String(histBuf[idx].packV,2);if(k<histCount-1)s+=",";}
  s+="],\"packI\":[";
  for(uint16_t k=0;k<histCount;k++){uint16_t idx=(start+k)%HIST_SIZE;s+=String(histBuf[idx].packI,2);if(k<histCount-1)s+=",";}
  s+="],\"soc\":[";
  for(uint16_t k=0;k<histCount;k++){uint16_t idx=(start+k)%HIST_SIZE;s+=String(histBuf[idx].soc,1);if(k<histCount-1)s+=",";}
  s+="],\"cells\":[";
  for(uint8_t c=0;c<6;c++){
    s+="[";
    for(uint16_t k=0;k<histCount;k++){uint16_t idx=(start+k)%HIST_SIZE;s+=String(histBuf[idx].cell[c],3);if(k<histCount-1)s+=",";}
    s+="]";if(c<5)s+=",";
  }
  s+="]}";
  return s;
}

// =====================================================================
// WEB DASHBOARD
// =====================================================================
void handleRoot(){
  String html=R"rawhtml(
<!DOCTYPE html><html><head>
<meta charset='utf-8'><meta name='viewport' content='width=device-width,initial-scale=1'>
<title>ESP32 BMS Dashboard</title>
<script src='https://cdnjs.cloudflare.com/ajax/libs/Chart.js/4.4.1/chart.umd.js'></script>
<style>
  *{box-sizing:border-box;margin:0;padding:0}
  body{font-family:sans-serif;background:#0f172a;color:#e2e8f0;padding:16px}
  h1{font-size:18px;font-weight:500;margin-bottom:16px;color:#94a3b8}
  .cards{display:grid;grid-template-columns:repeat(auto-fit,minmax(130px,1fr));gap:10px;margin-bottom:20px}
  .card{background:#1e293b;border-radius:10px;padding:12px 14px}
  .card .lbl{font-size:11px;color:#64748b;margin-bottom:4px}
  .card .val{font-size:22px;font-weight:500;color:#f1f5f9}
  .card .unit{font-size:12px;color:#94a3b8;margin-left:2px}
  .charts{display:grid;grid-template-columns:1fr 1fr;gap:14px;margin-bottom:20px}
  @media(max-width:600px){.charts{grid-template-columns:1fr}}
  .chart-box{background:#1e293b;border-radius:10px;padding:14px}
  .chart-box h3{font-size:12px;color:#64748b;margin-bottom:10px;font-weight:400}
  .cells{display:grid;grid-template-columns:repeat(6,1fr);gap:8px;margin-bottom:16px}
  .cell{background:#1e293b;border-radius:8px;padding:10px 6px;text-align:center}
  .cell .cv{font-size:15px;font-weight:500}
  .cell .cl{font-size:10px;color:#64748b;margin-top:2px}
  .cell.bal{border:1px solid #f59e0b}
  .soc-bar{height:14px;background:#0f172a;border-radius:7px;overflow:hidden;margin-top:6px}
  .soc-fill{height:100%;border-radius:7px;transition:width .4s}
  .footer{font-size:11px;color:#475569;text-align:center;margin-top:8px}
  .ctrl{display:flex;gap:8px;margin-bottom:16px;flex-wrap:wrap}
  .btn{background:#1e293b;border:1px solid #334155;color:#94a3b8;padding:6px 14px;border-radius:6px;cursor:pointer;font-size:12px}
  .btn:hover{background:#334155}
  .btn.on{border-color:#22c55e;color:#22c55e}
</style>
</head><body>
<h1>ESP32 BMS — Live Dashboard</h1>
<div class='cards'>
  <div class='card'><div class='lbl'>Pack voltage</div><div class='val' id='pv'>—<span class='unit'>V</span></div></div>
  <div class='card'><div class='lbl'>Current</div><div class='val' id='pi'>—<span class='unit'>A</span></div></div>
  <div class='card'>
    <div class='lbl'>SOC — Coulomb</div>
    <div class='val' id='soc'>—<span class='unit'>%</span></div>
    <div class='soc-bar'><div class='soc-fill' id='socbar' style='width:0%;background:#22c55e'></div></div>
  </div>
  <div class='card'><div class='lbl'>SOC — voltage</div><div class='val' id='socv'>—<span class='unit'>%</span></div></div>
  <div class='card'><div class='lbl'>Charged</div><div class='val' id='chAh'>—<span class='unit'>Ah</span></div></div>
  <div class='card'><div class='lbl'>Discharged</div><div class='val' id='dcAh'>—<span class='unit'>Ah</span></div></div>
</div>
<div class='ctrl'>
  <button class='btn' onclick="fetch('/balance/off')">All balance OFF</button>
  <button class='btn' id='btnBal' onclick="toggleBal()">Auto balance</button>
</div>
<div class='cells' id='cellGrid'></div>
<div class='charts'>
  <div class='chart-box'><h3>SOC % (Coulomb counting)</h3><div style='position:relative;height:160px'><canvas id='cSOC'></canvas></div></div>
  <div class='chart-box'><h3>Pack voltage (V)</h3><div style='position:relative;height:160px'><canvas id='cV'></canvas></div></div>
  <div class='chart-box'><h3>Pack current (A)</h3><div style='position:relative;height:160px'><canvas id='cI'></canvas></div></div>
  <div class='chart-box'><h3>Cell voltages (V)</h3><div style='position:relative;height:160px'><canvas id='cCells'></canvas></div></div>
</div>
<div class='footer' id='ft'>Connecting…</div>
<script>
const COLORS=['#38bdf8','#4ade80','#fb923c','#f472b6','#a78bfa','#facc15'];
const MAX_PTS=120;let autoBalOn=false;
function mkChart(id,label,color,yMin,yMax){return new Chart(document.getElementById(id),{type:'line',data:{labels:[],datasets:[{label,data:[],borderColor:color,borderWidth:1.5,pointRadius:0,fill:false,tension:0.3}]},options:{responsive:true,maintainAspectRatio:false,animation:false,scales:{x:{display:false},y:{min:yMin??undefined,max:yMax??undefined,ticks:{color:'#94a3b8',font:{size:10}},grid:{color:'rgba(255,255,255,.05)'}}},plugins:{legend:{display:false}}}});}
function mkCellChart(id){return new Chart(document.getElementById(id),{type:'line',data:{labels:[],datasets:COLORS.map((c,i)=>({label:'C'+(i+1),data:[],borderColor:c,borderWidth:1.2,pointRadius:0,fill:false,tension:0.3}))},options:{responsive:true,maintainAspectRatio:false,animation:false,scales:{x:{display:false},y:{ticks:{color:'#94a3b8',font:{size:10}},grid:{color:'rgba(255,255,255,.05)'}}},plugins:{legend:{labels:{color:'#94a3b8',font:{size:10},boxWidth:8}}}}});}
const socChart=mkChart('cSOC','SOC','#22c55e',0,100);
const vChart=mkChart('cV','V','#38bdf8',null,null);
const iChart=mkChart('cI','A','#fb923c',null,null);
const cellChart=mkCellChart('cCells');
function push(chart,label,...vals){chart.data.labels.push(label);if(chart.data.labels.length>MAX_PTS)chart.data.labels.shift();vals.forEach((v,i)=>{chart.data.datasets[i].data.push(v);if(chart.data.datasets[i].data.length>MAX_PTS)chart.data.datasets[i].data.shift();});chart.update('none');}
function socColor(s){return s>50?'#22c55e':s>20?'#f59e0b':'#ef4444';}
function toggleBal(){autoBalOn=!autoBalOn;fetch('/balance/auto/'+(autoBalOn?'on':'off'));document.getElementById('btnBal').className='btn'+(autoBalOn?' on':'');}
let lastSamples=0;
async function tick(){
  try{
    const d=await(await fetch('/api/status')).json();const t=new Date().toLocaleTimeString();
    document.getElementById('pv').childNodes[0].textContent=d.pack_voltage.toFixed(2);
    document.getElementById('pi').childNodes[0].textContent=d.pack_current.toFixed(2);
    const s=parseFloat(d.soc_cc);
    document.getElementById('soc').childNodes[0].textContent=s.toFixed(1);
    document.getElementById('socv').childNodes[0].textContent=parseFloat(d.soc_v).toFixed(1);
    document.getElementById('chAh').childNodes[0].textContent=parseFloat(d.charged_ah).toFixed(3);
    document.getElementById('dcAh').childNodes[0].textContent=parseFloat(d.discharged_ah).toFixed(3);
    const bar=document.getElementById('socbar');bar.style.width=s.toFixed(1)+'%';bar.style.background=socColor(s);
    const grid=document.getElementById('cellGrid');
    if(grid.children.length===0)for(let i=0;i<6;i++){const c=document.createElement('div');c.id='cell'+i;c.className='cell';c.innerHTML=`<div class='cv' id='cv${i}'>—</div><div class='cl'>Cell ${i+1}</div>`;grid.appendChild(c);}
    d.cell_voltages.forEach((v,i)=>{document.getElementById('cv'+i).textContent=v.toFixed(3);document.getElementById('cell'+i).className='cell'+(d.balance[i]?' bal':'');});
    if(d.samples!==lastSamples){
      push(socChart,t,s);push(vChart,t,d.pack_voltage);push(iChart,t,d.pack_current);
      cellChart.data.labels.push(t);if(cellChart.data.labels.length>MAX_PTS)cellChart.data.labels.shift();
      d.cell_voltages.forEach((v,i)=>{cellChart.data.datasets[i].data.push(v);if(cellChart.data.datasets[i].data.length>MAX_PTS)cellChart.data.datasets[i].data.shift();});
      cellChart.update('none');lastSamples=d.samples;
    }
    document.getElementById('ft').textContent='Updated '+t+' | Samples: '+d.samples;
  }catch(e){document.getElementById('ft').textContent='Connection error — retrying…';}
}
tick();setInterval(tick,1000);
</script>
</body></html>
)rawhtml";
  server.send(200,"text/html",html);
}
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
void loop(){
  static unsigned long lastSample=0,lastPrint=0,lastMqtt=0,lastRecon=0;
  static bool ledState=false;
  unsigned long now=millis();

  if(now-lastSample>=300){
    lastSample=now;sampleAllChannels();
    if(PIN_STATUS_LED>=0){ledState=!ledState;digitalWrite(PIN_STATUS_LED,ledState);}
  }
  if(now-lastPrint>=printIntervalMs){lastPrint=now;printSerialReport();}

  if(mqttEnabled&&!mqttClient.connected()&&now-lastRecon>=10000){lastRecon=now;mqttReconnect();}
  if(mqttEnabled&&mqttClient.connected()){
    if(now-lastMqtt>=MQTT_PUBLISH_INTERVAL_MS){lastMqtt=now;mqttPublishAll();}
    mqttClient.loop();
  }
  server.handleClient();
}

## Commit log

2026-04-26 Add ESP32 BMS with web dashboard and coulomb counting
2026-04-26 Create esp32-bms-firmware
2026-04-27 Enhance README with MQTT setup and usage details
    Added detailed documentation for the ESP32 BMS firmware with MQTT support, including setup instructions, configuration details, and integration with Home Assistant.
2026-04-27 Enhance README with setup and usage details
    Added detailed README for ESP32 BMS firmware, including setup instructions, requirements, configuration, and usage.
2026-04-27 Revise README with project details and structure
    Updated project name and added detailed project overview, status, repository structure, system functionality, hardware overview, firmware details, MQTT data format, ML pipeline plans, quick start gui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
2026-04-27 Update comments and formatting in esp32_bms_coulomb.cpp
2026-04-27 Update fmt.Println message from 'Hello' to 'Goodbye'
